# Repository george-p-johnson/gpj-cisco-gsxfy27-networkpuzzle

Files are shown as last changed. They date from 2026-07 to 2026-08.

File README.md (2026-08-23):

# Arduino Resistor Match Question/Answer Game: System Reference & Guide

> **This file describes the original single-board prototype and is out of date.** The live installation runs six boards driven by a shared `answer_table.tsv` answer key (not the hardcoded `correctAnswers[3]` array below), plus a networked remote controller and admin status page. See [`question_game/CLAUDE.md`](question_game/CLAUDE.md) for the current system, and [`remote_controller/README.md`](remote_controller/README.md) for the remote controller / admin page. The electrical design, ADC signal processing, and calibration math below (Sections 2-4) are still accurate and unchanged.

This file provides the comprehensive architectural, electrical, mathematical, and programmatic specification for the 3-Channel Resistor Match Question/Answer Game powered by the **Waveshare ESP32-S3** microcontroller. It is fully self-contained and serves as the single source of truth for understanding, modifying, or reproducing this system.

---

## 1. System Overview & Game Mechanics

The project implements a hardware-based, tactile matching game featuring **three question sockets** (channels) and corresponding **answer sockets**. 

* **The Patch Cord Interface:** A physical patch cord (carrying an embedded test resistor representing the selected answer) is plugged between a question socket and an answer socket.
* **Continuous Scanning:** The microcontroller continuously scans the three question sockets to identify which answer resistor (if any) is currently connected.
* **Match Indicator LEDs:** Each channel has a dedicated bi-color LED:
  - **Green LED:** Illuminates when the patch cord connects a question socket to its **correct** answer socket (as defined in software).
  - **Red LED:** Illuminates if the patch cord is connected to an **incorrect** answer socket, or is **unplugged** (open circuit).
* **Game Victory State:** A game-wide success signal is triggered only when all three channels have correct matches simultaneously.
* **Variable Configurations:** To allow questions to change dynamically from game to game, correct answers are stored in a simple, editable software array. This enables rapid game reconfigurability without any hardware rewiring.

---

## 2. Hardware Architecture & Electrical Design

The system determines matches by measuring the voltage drop across a custom voltage divider network.

### A. Circuit Diagram
Each of the three channels utilizes an identical, noise-insulated voltage divider circuit designed to stabilize readings and prevent capacitive/electrostatic interference:

```
                  +3.3V (VCC)
                    |
              [ 10k Ω Fixed ]  <--- Top Reference Resistor (R_top)
                    |
                    +-------------------> ESP32-S3 Analog Pin (GPIO 1, 2, or 3)
                    |               |
             [ Test Resistor ]   [ 100k Ω ] <--- Permanent Pull-Down Resistor (R_PD)
                 (R_test)          (R_PD)
                    |               |
                   GND             GND
```

### B. Component Role & Optimization Choices
* **Top Reference Resistor ($R_{\text{top}}$) = $10\text{ k}\Omega$:** Sits at the geometric center of our target resistor range ($470\ \Omega$ to $100\text{ k}\Omega$). This balances voltage step intervals across low and high values, preventing low-value resistors from falling into the ground noise floor and high-value resistors from compressing near the ADC saturation ceiling.
* **Permanent Pull-Down Resistor ($R_{\text{PD}}$) = $100\text{ k}\Omega$:** 
  - Prevents the analog pin from floating when a patch cord is unplugged. 
  - Forms a baseline voltage divider when the socket is empty (Open Circuit), locking the baseline reading cleanly at $\approx 3040\text{ mV}$.
  - Pulls high-end test values down, expanding the spacing between the highest resistor ($100\text{ k}\Omega$) and an open circuit into a wide, easily detectable $+238\text{ mV}$ gap.
* **Test Socket Resistor ($R_{\text{test}}$):** Placed in the answer socket. When plugged, it sits in parallel with the $100\text{ k}\Omega$ pull-down.

### C. Mathematical Model
When a patch cord is inserted, the lower resistance branch ($R_{\text{bottom}}$) becomes the parallel combination of the test resistor ($R_{\text{test}}$) and the permanent pull-down ($R_{\text{PD}}$):

$$R_{\text{bottom}} = \frac{R_{\text{test}} \times 100,000}{R_{\text{test}} + 100,000}$$

The voltage output ($V_{\text{out}}$) delivered to the ESP32-S3 ADC is:

$$V_{\text{out}} = 3300\text{ mV} \times \frac{R_{\text{bottom}}}{10,000 + R_{\text{bottom}}}$$

---

## 3. Signal Processing & ESP32-S3 ADC Workarounds

The ESP32-S3 features a successive-approximation register (SAR) ADC. Utilizing this hardware reliably across multiple rapid channels requires specific software workarounds.

### A. Multiplexer Residual Charge Flush
* **The Issue:** The ESP32-S3 shares a single internal ADC across its input pins. Rapidly switching the internal multiplexer between pins causes residual capacitive charge from the previous pin to leak into the next channel's measurement, producing false matches.
* **The Solution:** The reading function performs a single "throwaway" read (`analogReadMilliVolts(pin)`) and pauses for $100\ \mu\text{s}$ (`delayMicroseconds(100)`) to allow the multiplexer's internal capacitance to fully discharge before sampling.

### B. ADC Settings & Filtering
* **ADC Settings:** 12-bit resolution (`0` to `4095`) and $11\text{dB}$ attenuation (`ADC_11db`), mapping the input range across the full $0\text{V} - 3.3\text{V}$ scale.
* **Filtering Noise:** To smooth high-frequency voltage fluctuations and EMI, the software averages 15 separate ADC samples over a $15\text{ms}$ interval for each channel.
* **Noise Floor:** Any voltage reading below $75\text{ mV}$ is explicitly discarded as skin-touch capacitive noise or stray ground loop voltage and mapped to `NONE`.

---

## 4. Adaptive Calibration & Auto-Span Architecture

Rather than relying on brittle, hardcoded threshold numbers, the firmware implements a professional, self-normalizing hardware-calibration pipeline.

### A. Measured Ranges Database
Your raw, physical measurements are stored as a static array of range structures (`minMV` and `maxMV`) normalized to a standard $3300\text{ mV}$ rail scale:

| Resistor Class | Your Empirical Range | Calculated Gap Midpoint |
| :--- | :---: | :---: |
| **Noise / Touch** | $0 - 74\text{ mV}$ | — |
| **$470\ \Omega$** | $112 - 186\text{ mV}$ | $218\text{ mV}$ |
| **$1\text{ k}\Omega$** | $250 - 326\text{ mV}$ | $432\text{ mV}$ |
| **$2.2\text{ k}\Omega$** | $539 - 608\text{ mV}$ | $787\text{ mV}$ |
| **$4.7\text{ k}\Omega$** | $967 - 1041\text{ mV}$ | $1283\text{ mV}$ |
| **$10\text{ k}\Omega$** | $1525 - 1596\text{ mV}$ | $1837\text{ mV}$ |
| **$22\text{ k}\Omega$** | $2078 - 2131\text{ mV}$ | $2215\text{ mV}$ |
| **$33\text{ k}\Omega$** | $2300 - 2374\text{ mV}$ | $2387\text{ mV}$ |
| **$47\text{ k}\Omega$** | $2401 - 2551\text{ mV}$ | $2583\text{ mV}$ |
| **$68\text{ k}\Omega$** | $2615 - 2682\text{ mV}$ | $2703\text{ mV}$ |
| **$100\text{ k}\Omega$** | $2725 - 2803\text{ mV}$ | $2921\text{ mV}$ |
| **NONE (Open)** | $\approx 3040\text{ mV}$ | $> 2921\text{ mV}$ |

You can easily tweak these ranges directly inside the `nominalRanges[]` array in the Arduino IDE if physical components are changed!

### B. Runtime Boundary Calculation & Threshold Bias
The software automatically calculates decision boundaries between adjacent resistors at runtime:
$$\text{Threshold}[i] = \text{Max}_i + (\text{Min}_{i+1} - \text{Max}_i) \times \text{THRESHOLD\_BIAS}$$

* **`THRESHOLD_BIAS` parameter (Default: `0.3`):** This customizable constant defines where the boundary is placed within the unassigned gaps.
  - Setting it to `0.5` places boundaries exactly in the mathematical center (midpoint).
  - Setting it to `0.3` biases thresholds lower in the gap (closer to the lower resistor). This gives the higher resistor a massive **downward safety cushion** to tolerate loose wires, power supply dips, or resistor tolerances without misclassifying!

### C. Continuous & Startup Auto-Span Calibration
To completely neutralize chip-to-chip and pin-to-pin ADC gain variations, the software runs an intelligent calibration loop:

1. **Boot-Time reference Scan:** When the ESP32-S3 starts, the program scans all three pins. If you boot with patch cables already plugged in, it searches for any **single empty pin** (reading $> 2850\text{ mV}$) to compute the chip's global scale factor and instantly calibrates *all three* channels on startup. If all three channels are plugged on boot, it defaults to a scale factor of `1.0`.
2. **Continuous Normalization:** Whenever a pin becomes empty during gameplay, the system dynamically measures the raw open-circuit voltage $V_{\text{raw\_open}}$ and updates its scale multiplier.
3. **Aligned Target:** The calibration standard target is aligned to **`3040.0 mV`** (your physical board's natural open baseline). This ensures that on your hardware, the scale factors naturally calibrate to exactly `1.0`, resulting in $100\%$ consistent behavior whether you boot with cables plugged or unplugged:
$$\text{scaleFactor}[i] = \frac{3040.0}{V_{\text{raw\_open}}[i]}$$
All subsequent resistor readings on Pin $i$ are multiplied by `scaleFactor[i]` before classification. This guarantees that all three sockets behave identically on any physical board!

---

## 5. Hardware Pin Mapping

The system relies on three discrete analog inputs and six digital output pins mapped to physical bi-color LEDs.

| Channel | physical Socket | ESP32-S3 Pin | LED RED GPIO | LED GREEN GPIO | Physical Header Pins & Location |
| :---: | :---: | :---: | :---: | :---: | :--- |
| **CH1** | Socket 1 | **GPIO 1** | **GPIO 16** | **GPIO 17** | Left Header Pins 32, 34 |
| **CH2** | Socket 2 | **GPIO 2** | **GPIO 38** | **GPIO 39** | Right Header Pins 14, 12 |
| **CH3** | Socket 3 | **GPIO 3** | **GPIO 34** | **GPIO 35** | Right Header Pins 19, 17 |

*Note: LED pins output digital `HIGH` to switch the selected color ON, and `LOW` to switch it OFF. Red and Green pins are operated mutually-exclusively per channel.*

---

## 6. Software Architecture & Game Flow

The game is structured using a simple polling-loop state machine. 

### A. Variable Array Structure
The core flexibility requirement is achieved through the global configuration array `correctAnswers[3]`. Each element stores the target resistor index corresponding to a specific channel:

```cpp
// Target resistor index matching table (0 = 470, 1 = 1k, ... 9 = 100k)
int correctAnswers[3] = {
  3,  // CH1 expects 4.7k (Index 3)
  7,  // CH2 expects 47k  (Index 7)
  5   // CH3 expects 22k  (Index 5)
};
```

### B. Logic Processing Flow
On every iteration of the `loop()`:
1. **Reset Victory Tracker:** A boolean flag `allCorrect` is initialized to `true`.
2. **Channel Polling:** For each channel `i` from `0` to `2`:
   - Measure the smoothed analog voltage ($V_{\text{out}}$) on `ANALOG_PINS[i]` after flushing the charge.
   - Map the voltage value to its resistor classification index `detectedIndex` using the Midpoint Decision boundaries.
   - Compare `detectedIndex` with the target `correctAnswers[i]`.
   - Update LEDs:
     - If matched (`detectedIndex == correctAnswers[i]`), set Green Pin `HIGH` and Red Pin `LOW`.
     - If mismatched or unplugged, set Red Pin `HIGH` and Green Pin `LOW`, and toggle `allCorrect = false`.
   - Output Serial telemetry details (measured mV, detected resistor name, match status).
3. **Master Win Assertion:** If `allCorrect` remains `true` after polling all three channels, output the unified game win telemetry (`*** GAME SOLVED: ALL PATCHES CORRECT! ***`).
4. **Throttle Delay:** A final $300\text{ms}$ delay throttles the scanning loop to conserve processing cycles and provide human-readable serial logs.

---

## 7. Operational Instructions for Game Administrators

### Changing Answers for a New Game
To re-index answers for a brand new game session:
1. Choose which physical answer resistor value should match each physical question socket (CH1, CH2, CH3).
2. Look up each resistor's **Index** from the **Adaptive Calibration & Auto-Span Database** (Section 4).
3. Locate the `correctAnswers[3]` array near the top of `question_game.ino`.
4. Update the indices in the array. For example, if you want:
   - CH1 to match $1\text{ k}\Omega$ (Index `1`)
   - CH2 to match $100\text{ k}\Omega$ (Index `9`)
   - CH3 to match $2.2\text{ k}\Omega$ (Index `2`)
   
   Modify the line to:
   ```cpp
   int correctAnswers[3] = { 1, 9, 2 };
   ```
5. Upload the sketch to the ESP32-S3 Dev Board. No physical circuit changes are necessary.

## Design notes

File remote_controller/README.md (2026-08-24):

# Remote Controller

A small web app for operating the GSXFY27 Network Puzzle game from a phone,
tablet, or laptop on the same network as the show PC.

- 3 toggle buttons: **Activate Player 1 / 2 / 3** (only enabled while the game state is Idle *and* that player's boards are online -- Player 1 needs boards 1/2, Player 2 needs boards 3/4, Player 3 needs boards 5/6; shows "NO BOARDS" otherwise)
- 2 pulse buttons: **Start Game** (only enabled while the game state is Idle, at least one player is active, *and* no board has a patch cord still plugged in from the previous game -- shows a docent-facing reminder naming exactly which player/question is still connected, e.g. "Player 2 Q4", otherwise), **Reset Game** (also auto-activates any player not already ON *and* whose boards are online, so a fresh reset defaults to all reachable players ready)
- A live **Connected / Disconnected** indicator for the link to TouchDesigner
- A live **game state** display (Idle / Three / Two / One / Start / Gameplay / Results)
- A live **Boards** indicator showing which of the 6 ESP32 question boards are currently reporting, grouped by panel
- A **Show Answer Key** toggle, collapsed by default, revealing each player's Q1-Q6 answer socket and resistor value (e.g. "Q3 -> Socket A7, 47kΩ") for a docent to reference on the floor. Read once from `answer_table.tsv` at server launch (same restart-to-reload caveat as the admin page's answer data, see below) and sent to every client on the public page -- deliberately not admin-gated, since the docent is this page's primary user, even though the page is also reachable off the LAN per `DEPLOYMENT.md`.

It runs as a small Node.js server on the same Windows PC as TouchDesigner:
the server hosts the control page over plain HTTP/WebSocket for any device
on the LAN, and separately speaks OSC/UDP to TouchDesigner (matching the
OSC convention the ESP32 boards already use, on different ports so it never
touches port 9000).

```
Browser  <--WebSocket-->  Node server  <--OSC/UDP-->  TouchDesigner
(any LAN device)          (this PC)                    (this PC)
```

## Setup

```bash
npm install
cp .env.example .env
```

Edit `.env` if you want a different HTTP port (default `8080`) or different
OSC ports. See [`.env.example`](.env.example) for all options.

## Run

```bash
npm start
```

The console prints the URLs to use:

```
Local:   http://localhost:8080
Network: http://192.168.x.x:8080
```

Open the `Network` URL from any phone/tablet/laptop on the same network as
the show PC.

## TouchDesigner side

See [`touchdesigner/SETUP.md`](touchdesigner/SETUP.md) for the OSC In DAT /
Callbacks DAT / heartbeat wiring needed inside the `.toe` to receive
commands and report connection status back.

## Show PC deployment

See [`DEPLOYMENT.md`](DEPLOYMENT.md) for how this is made reachable from
outside the LAN (Cloudflare Tunnel, `https://gsxnetworkpuzzle.com`) and how
the show PC autostarts everything, with crash auto-recovery
(`../START_CISCO_NETWORK_PUZZLE.bat` + Task Scheduler).

## Message reference

| UI action | OSC address (Remote → TD) | Value |
| --- | --- | --- |
| Toggle Player 1/2/3 | `/remote/player/1`, `/2`, `/3` | `1` = on, `0` = off |
| Start Game | `/remote/start_game` | `1` |
| Reset Game | `/remote/reset_game` | `1` |
| Open Monitors *(admin page only)* | `/remote/open_monitors` | `1` |
| Reset Best Time *(admin page only)* | `/remote/reset_best_time` | `1` |

Reset Game also triggers up to three additional `/remote/player/<n>` = `1`
messages right after it (staggered `PLAYER_ACTIVATE_STAGGER_MS` apart, see
`.env.example`) — one for each player not already active, so TD sees the
same activation messages it would if someone had toggled them by hand.

| TD → Remote | OSC address | Purpose |
| --- | --- | --- |
| Heartbeat | `/remote/heartbeat` | Sent ~every 1s; drives Connected/Disconnected |
| Game state | `/remote/game_state` | Int `1`-`7`; drives the game-state display |
| Player active | `/remote/player_active` | 3 ints `[p1, p2, p3]` as 0/1; authoritative -- overwrites the server's local player state on receipt (see below) |
| Player result | `/remote/player_result` | 3 ints `[p1, p2, p3]`, placement code `0`-`3`: `0` = Try Again, `1` = Winner, `2` = 2nd place, `3` = 3rd place. TD flips `1`-`3` live per player as they finish during Gameplay; `0` is set for anyone still unfinished at the Gameplay->Results boundary once time runs out. Drives the WINNER/2ND PLACE/3RD PLACE/TRY AGAIN label on each active player's button, shown only while game state is Gameplay or Results (otherwise the plain ON/OFF/NO BOARDS label is shown, ignoring any stale placement from a previous round) |
| Board status | `/remote/waveshare/1` ... `/remote/waveshare/6` | `1` = board reporting recently, `0` = stale/offline; drives the Boards indicator, and (paired up) the per-player `boardsReady` flags below |
| Board detail | `/remote/waveshare_detail/1` ... `/6` | 3 ints: `ch1Index, ch2Index, ch3Index` (0-10 resistor classification, see below) -- raw per-channel readings power the private admin status page only |

Board status also drives a public, non-admin-gated `boardsReady` map in the
state broadcast: Player 1 is ready only when boards 1 *and* 2 are both
reporting, Player 2 needs boards 3/4, Player 3 needs boards 5/6 (same
board->panel mapping as `question_game/CLAUDE.md` Section 6D). A player
whose boards aren't ready has its **Activate Player N** button disabled
(shown as "NO BOARDS") even while the game state is Idle, and is skipped by
Reset Game's auto-activate. The server also rejects a `toggle` trying to
turn that player ON outright, so this can't be bypassed by a stale/cached
page -- though an already-active player can still be toggled back OFF if its
boards drop out mid-idle.

Board detail also drives two public, non-admin-gated derived fields:
* `anyConnected` -- `true` whenever any channel on any board reads other
  than `10` (NONE) -- i.e. something is still plugged in somewhere. This
  blocks the **Start Game** button and shows the docent reminder above
  (server also rejects a `start_game` pulse outright while it's true, so
  this can't be bypassed by a stale/cached page).
* `connectedCables` -- an array of `{ player, question }` pairs (question
  `1`-`6`) naming exactly which sockets are still plugged in, rendered under
  the docent reminder (e.g. "Player 2 Q4, Player 3 Q1"). Both fields are
  presence-only -- neither reveals which resistor is plugged in or whether
  it's correct, so both are safe to send to every connected client, not just
  admin ones.

Resistor classification index (same 0-10 scale the ESP32 firmware uses and
the admin page translates to a label -- see `public-admin/app.js`
`RESISTOR_LABELS`):

| Index | Resistor |
| :---: | --- |
| 0 | 470Ω |
| 1 | 1kΩ |
| 2 | 2.2kΩ |
| 3 | 4.7kΩ |
| 4 | 10kΩ |
| 5 | 22kΩ |
| 6 | 33kΩ |
| 7 | 47kΩ |
| 8 | 68kΩ |
| 9 | 100kΩ |
| 10 | NONE (socket empty / open circuit) |

Game state values:

| Value | State |
| :---: | --- |
| 1 | Idle |
| 2 | Three |
| 3 | Two |
| 4 | One |
| 5 | Start |
| 6 | Gameplay |
| 7 | Results |

Toggle state and the last-known game state are held centrally on the Node
server, so every connected browser stays in sync if more than one person
has the page open. Player state specifically is also confirmed by TD
(`/remote/player_active`, not just assumed from the last command the server
sent) -- otherwise a server restart would show every player OFF regardless
of what TD actually had active, since the server's own memory resets to
all-OFF on startup. See `touchdesigner/SETUP.md` Section 5c for the TD-side
wiring.

## Private admin status page

`public-admin/` is a second, separate page showing each board's live
resistor-classification reading per question (Q1-Q3 or Q4-Q6 depending on
the board, translated from the 0-10 index to a resistor value, e.g. "33kΩ"),
grouped by Player 1/2/3 -- e.g. to check whether Q4 on Player 2's boards is
plugged into the right resistor. It also carries the
**Open Monitors** and **Reset Best Time** pulse buttons, moved here from the
public control page since they're maintenance actions, not something a
random visitor to the public URL should be able to trigger. TD only sends the raw
classification (no match data), so the server reads the correct-answer key
itself: once at launch, from `answer_table.tsv` at the repo root (the same
file the ESP32 boards' SD cards read from -- see `server.js`
`loadAnswerIndex()`) and sends it to admin clients alongside the live
readings. **Editing `answer_table.tsv` needs a server restart to take
effect** -- it's read once at startup, not watched for changes. It's only
served to requests whose `Host` header matches `ADMIN_HOSTNAME` (`.env`, default
`admin.gsxnetworkpuzzle.com`); any other hostname never sees that directory.
See `touchdesigner/SETUP.md` Section 4b for the TD-side wiring this needs,
and `DEPLOYMENT.md` for exposing it as its own subdomain through the
Cloudflare Tunnel.

Every response served on the admin hostname carries `Cache-Control: no-store`
(both browser and Cloudflare-edge caching disabled) -- this page changes
often during development, and a cached `app.js` will keep running old logic
against new data long after the server's been updated (e.g. rendering a
field the current code no longer sends). The public control page is
unaffected and keeps normal caching.

**`no-store` only prevents *new* staleness -- it doesn't retroactively clear
copies Cloudflare's edge had already cached from before that header
existed.** Confirmed in practice: after adding `no-store` and deploying an
`app.js` change, some clients still received the old file -- a hard refresh
on the affected device wasn't enough, but Cloudflare edge nodes are
per-location, so different visitors can be served from different (stale vs.
fresh) edges simultaneously. Fix: **Cloudflare dashboard → Caching →
Configuration → Purge Everything** (or a Custom Purge of
`admin.gsxnetworkpuzzle.com/*`). This is a global edge purge and needs
dashboard access -- there's no CLI/API token set up for it in this project,
so it has to be done manually when it comes up.

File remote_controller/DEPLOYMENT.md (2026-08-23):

# Show PC deployment: public access + autostart

This covers the parts of the setup that live outside the app itself: making
the remote controller reachable from a phone/iPad without needing to be on
the same network as the show PC, and getting everything running
automatically when the show PC boots.

## Why a public tunnel, not just the LAN

Convention center networks are frequently locked down in ways that break
plain LAN access between devices on the same Wi-Fi (client isolation is
common, specifically to stop one attendee's device from reaching another's)
-- and bringing your own router/AP to create a private LAN may not be
usable or permitted on the show floor. A Cloudflare Tunnel sidesteps this
entirely: the show PC makes an *outbound* connection to Cloudflare (almost
always allowed, even on locked-down guest networks), and the control device
just opens a normal HTTPS URL over its own internet connection (venue
Wi-Fi or cellular) -- neither device needs to reach the other directly, so
network topology at the venue stops mattering.

The tradeoff: this depends on the venue actually having usable outbound
internet. The travel router is the fallback if that turns out not to be
true on-site.

## Current setup

- **Public URL:** `https://gsxnetworkpuzzle.com` (domain registered on
  Namecheap, DNS hosted on Cloudflare, free plan)
- **Tunnel name:** `gsx-remote-controller`
- **Tunnel ID:** `39103a87-015e-4755-9714-8158f1eb55c2`
- **cloudflared config (used by the service):** `C:\ProgramData\Cloudflare\cloudflared\config.yml`
  (points the `gsxnetworkpuzzle.com` hostname at `http://127.0.0.1:8080`,
  i.e. the remote-controller server -- `127.0.0.1` specifically, not
  `localhost`; see the gotcha below)
- **Credentials file (service copy):** `C:\ProgramData\Cloudflare\cloudflared\39103a87-015e-4755-9714-8158f1eb55c2.json`
  (keep this private -- it's what authorizes the tunnel; if it ever leaks,
  delete the tunnel via the Cloudflare dashboard to revoke it)
- A second copy of both files lives under `C:\Users\Spaceship\.cloudflared\`
  from initial setup/manual testing -- harmless to leave, just not what the
  service actually reads.
- **cloudflared install:** `C:\Program Files (x86)\cloudflared\cloudflared.exe`
  (installed via `winget install --id Cloudflare.cloudflared -e`)
- Only the bare domain is routed (no `www`) -- that was a deliberate choice,
  not an oversight.

Runs as a **Windows service** (auto-starts at boot, and the Service Control
Manager can restart it automatically if it crashes -- more resilient than
launching it from a startup script, which has no self-healing if the
process dies mid-show).

### The two non-obvious gotchas that cost real time getting this working

**1. `cloudflared service install` does not support `--config`, and its
default config auto-discovery does not reliably find a config placed in
either the interactive user's `~/.cloudflared/` or (despite some
documentation implying otherwise) `C:\ProgramData\Cloudflare\cloudflared\`
when running under the `LocalSystem` account it installs as.** Passing
`--config` before `service install` is silently ignored -- its own
`--help` only documents an optional `[TOKEN]` argument (for
Cloudflare-dashboard-managed tunnels, not our locally-created named
tunnel). The service would start, show `RUNNING`, and never actually
connect to Cloudflare's edge (0 network connections, requests to the
public URL returned a `530` -- "no active connector") with no error
surfaced anywhere obvious.

**The fix:** point the service's actual launch command at the config file
directly, by editing its registry `ImagePath` (this is more reliable than
`sc.exe config Cloudflared binPath= "..."`, which is the "normal" way to
do this -- that command kept silently failing to apply, almost certainly
PowerShell mangling the nested quotes on their way to the native `sc.exe`
argument parser):

```powershell
# Run as Administrator
Set-ItemProperty -Path "HKLM:\SYSTEM\CurrentControlSet\Services\Cloudflared" -Name "ImagePath" `
  -Value '"C:\Program Files (x86)\cloudflared\cloudflared.exe" --config "C:\ProgramData\Cloudflare\cloudflared\config.yml" tunnel run'
Get-Process cloudflared | Stop-Process -Force
Start-Sleep -Seconds 2
Start-Service -Name Cloudflared
sc.exe qc Cloudflared   # BINARY_PATH_NAME should now show the full command with --config
```

**2. Use `127.0.0.1`, not `localhost`, in `config.yml`'s `service:` line.**
`localhost` can resolve differently (IPv4 vs IPv6 loopback) under the
`LocalSystem` account's network context than under an interactive user
session -- worked fine testing manually as a normal user, returned `502
Bad Gateway` (tunnel connected fine, couldn't reach the origin) once
running as the actual service. Switching to the literal `127.0.0.1`
resolved it.

### Recreating this from scratch (e.g. new PC, or the credentials leaked)

1. `cloudflared tunnel login` -- opens a browser, authorize against the
   Cloudflare account, select the zone (`gsxnetworkpuzzle.com`).
2. `cloudflared tunnel create <name>` -- writes a new credentials JSON to
   `~/.cloudflared/`.
3. `cloudflared tunnel route dns <name> gsxnetworkpuzzle.com` -- if this
   fails with "record already exists," delete the conflicting DNS record
   for the bare domain in the Cloudflare dashboard first (a parking-page
   record commonly gets imported automatically when a domain is first
   added to Cloudflare).
4. Create `C:\ProgramData\Cloudflare\cloudflared\` and place `config.yml`
   there (see the current one for the exact format -- `tunnel:`/
   `credentials-file:` pointing at the new tunnel's ID/JSON, `ingress`
   rule mapping `gsxnetworkpuzzle.com` → `http://127.0.0.1:8080` --
   **`127.0.0.1`, not `localhost`**), plus a copy of the credentials JSON
   in that same folder.
5. `cloudflared service install` (as Administrator) -- installs the
   service shell; don't expect it to actually work yet.
6. Apply the registry `ImagePath` fix from gotcha #1 above, then restart
   the service and confirm with `sc.exe qc Cloudflared` before trusting it.
7. Verify end-to-end: `Invoke-WebRequest https://gsxnetworkpuzzle.com`
   should return `200`, not `530` (dead tunnel) or `502` (tunnel up,
   origin unreachable).

## Admin status subdomain (`admin.gsxnetworkpuzzle.com`)

The remote controller's private per-socket status page (`public-admin/` --
see `touchdesigner/SETUP.md` Section 4b) is gated by hostname: it's only
served to requests whose `Host` header is exactly `ADMIN_HOSTNAME` (`.env`,
default `admin.gsxnetworkpuzzle.com`). Any other hostname -- including the
main public one -- gets the normal control page and never sees the admin
directory, so there's no path to guess. This is obscurity, not
authentication: anyone who learns the admin hostname can load it with no
login. Don't post/share it anywhere public.

Both hostnames route through the same tunnel to the same origin
(`http://127.0.0.1:8080` -- the Node server itself decides which page to
serve based on the `Host` header it receives), so adding the subdomain is
just another `ingress` rule + DNS route on the tunnel that already exists:

1. Add a second hostname rule to
   `C:\ProgramData\Cloudflare\cloudflared\config.yml`, **above** the
   catch-all `http_status:404` rule (ingress rules are matched top to
   bottom, first match wins):

   ```yaml
   tunnel: 39103a87-015e-4755-9714-8158f1eb55c2
   credentials-file: C:\ProgramData\Cloudflare\cloudflared\39103a87-015e-4755-9714-8158f1eb55c2.json

   ingress:
     - hostname: gsxnetworkpuzzle.com
       service: http://127.0.0.1:8080
     - hostname: admin.gsxnetworkpuzzle.com
       service: http://127.0.0.1:8080
     - service: http_status:404
   ```

2. Route DNS for the new hostname to the same tunnel:

   ```powershell
   cloudflared tunnel route dns gsx-remote-controller admin.gsxnetworkpuzzle.com
   ```

3. Restart the service so it picks up the new config:

   ```powershell
   Get-Process cloudflared | Stop-Process -Force
   Start-Sleep -Seconds 2
   Start-Service -Name Cloudflared
   ```

4. Verify: `https://admin.gsxnetworkpuzzle.com` should show the board status
   page; `https://gsxnetworkpuzzle.com` should still show the normal control
   page and must **not** show admin content at any path.

Local testing without touching the tunnel: `curl -H "Host: admin.gsxnetworkpuzzle.com" http://localhost:8080/`
serves the admin page directly from the Node server, no DNS/tunnel changes
needed.

## Autostart: `START_CISCO_NETWORK_PUZZLE.bat`

[`../START_CISCO_NETWORK_PUZZLE.bat`](../START_CISCO_NETWORK_PUZZLE.bat)
(project root; this is what's wired into Task Scheduler) launches, in order:
1. [`../run_server_watchdog.bat`](../run_server_watchdog.bat), in its own window.
2. A 3-second wait for the server to bind its ports.
3. [`../run_td_watchdog.bat`](../run_td_watchdog.bat), in its own window.

It does **not** launch the Cloudflare tunnel -- that's the Windows service
above, which starts independently at boot. Only add a tunnel line back into
this script if the service is ever uninstalled; running both at once means
two redundant tunnel processes.

### Why watchdog wrappers instead of launching node/TD directly

Neither the Node server nor TouchDesigner self-heals if it crashes mid-show
-- unlike the Cloudflare tunnel, which has Windows Service Control Manager
recovery. `run_server_watchdog.bat` and `run_td_watchdog.bat` each loop
`start /wait` around their respective process: if it ever exits for any
reason, the watchdog waits 5 seconds and relaunches it automatically,
logging each attempt with a timestamp so a crash loop is visible rather
than silent.

**This means closing the app itself doesn't stop it** -- the watchdog just
brings it back. To actually shut something down (e.g. end-of-night
teardown), close the **watchdog's own console window** first (titled "GSX
Remote Controller (watchdog)" / "TouchDesigner (watchdog)"), *then* close
the app. Closing them in the other order just makes the app pop back open.

### Wiring it to Task Scheduler

Create a task pointing at `START_CISCO_NETWORK_PUZZLE.bat` with trigger
**"At log on"** -- not the generic "At startup" trigger. A plain
system-startup trigger runs in Session 0, which has no visible desktop, so
none of these windows would actually appear. Also check **"Run only when
user is logged on"** in the task's General tab, for the same reason.

**Confirmed working** on a real reboot: the Task Scheduler task fired, the
server bound port 8080, TD launched with the project loaded, and TD's
heartbeat reached the server (remote page showed Connected/Idle) -- all
without any manual intervention.

### If the site is down and isn't coming back on its own

The auto-recovery above only works while the watchdog console window itself
is still running -- if *that* window got closed (crashed, closed by
accident, closed in the wrong order during a manual restart), the inner
`node server.js` process it was supervising has no way to come back on its
own, no matter how long you wait.

Check for both **before** assuming the server crashed for some deeper reason:
- Is a `node.exe` process bound to port 8080? (`netstat -ano | findstr ":8080"`)
- Is the **"GSX Remote Controller (auto-restart)"** console window still open?

If the node process is gone and so is its watchdog window, don't just run
`node server.js` directly -- that gets the site back up but leaves it
unsupervised again (a second crash won't self-heal). Instead relaunch the
watchdog script itself so recovery is restored:

```powershell
Start-Process -FilePath "run_server_watchdog.bat" -WorkingDirectory "C:\_projects\gpj-cisco-gsxfy27-networkpuzzle"
```

This has happened more than once with no clear root cause identified yet --
if it recurs, worth checking Windows Event Viewer for why the watchdog's
`cmd.exe` itself exited (a plain `:loop ... goto loop` batch script normally
never does, so something external likely killed it).

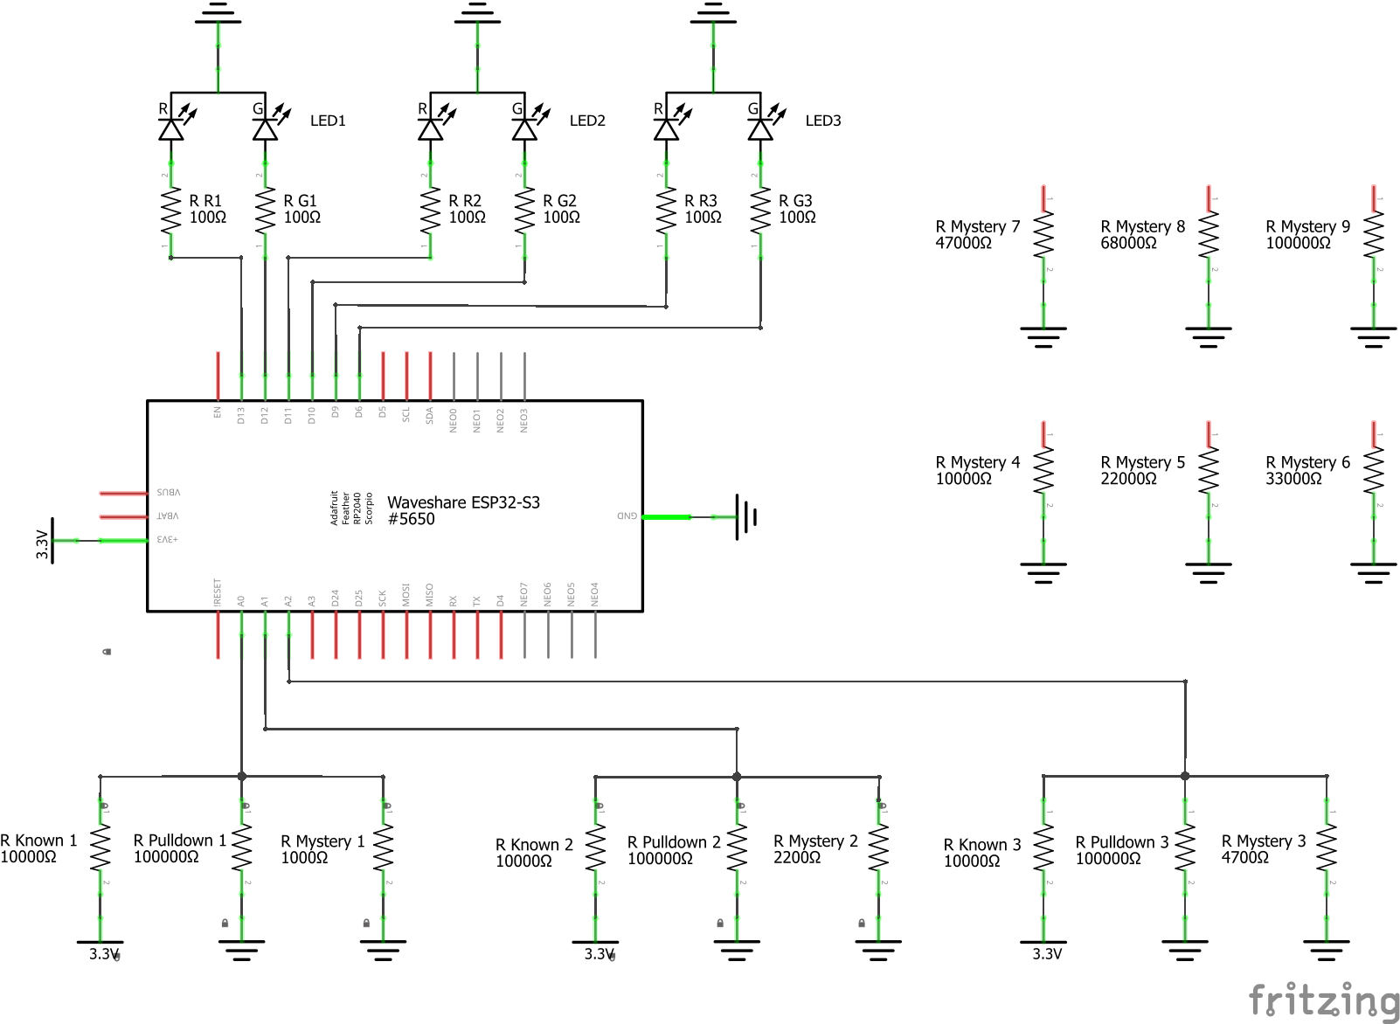
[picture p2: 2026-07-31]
Fritzing/schematic_schem.png

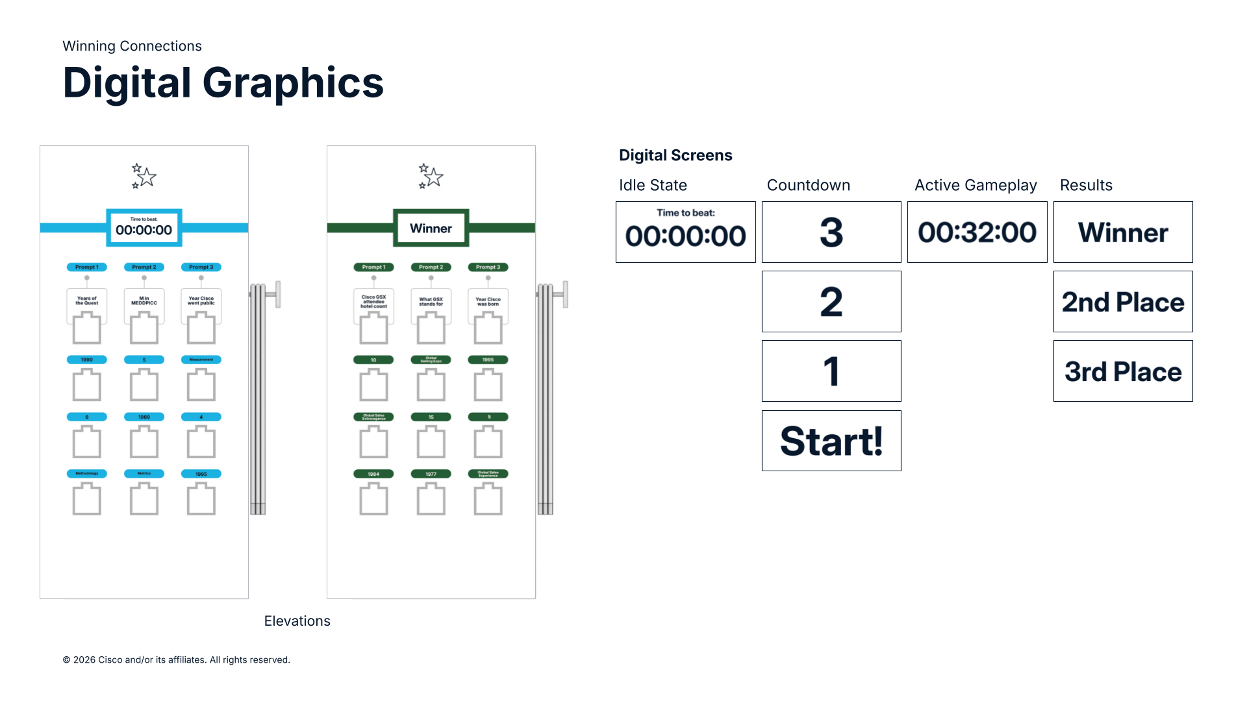
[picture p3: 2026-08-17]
reference/Digital-Graphics.png

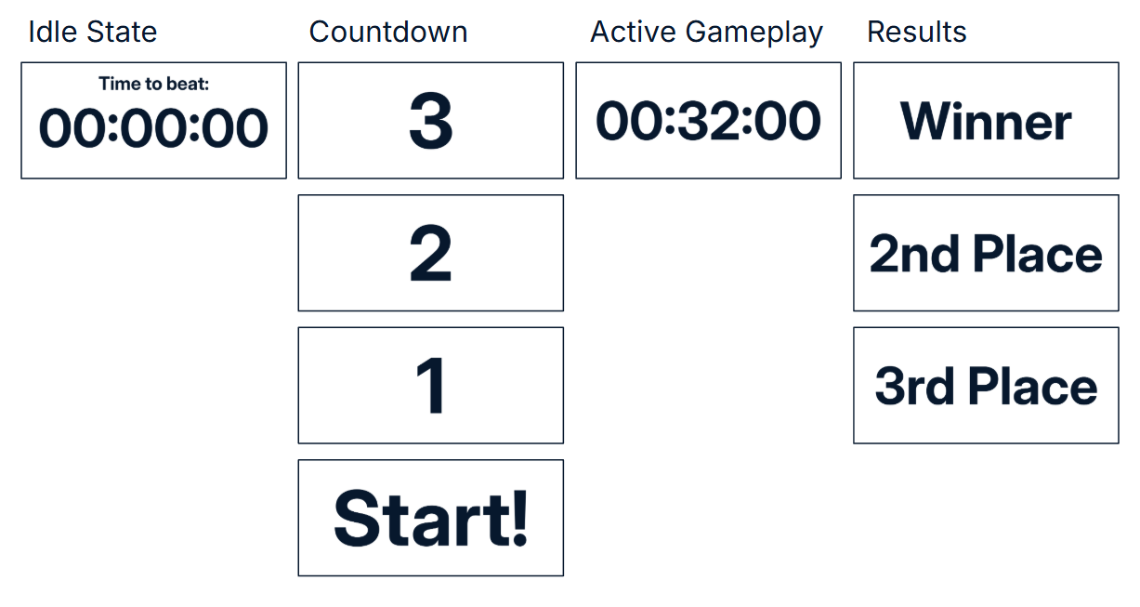
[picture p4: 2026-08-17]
reference/screenlayout.png

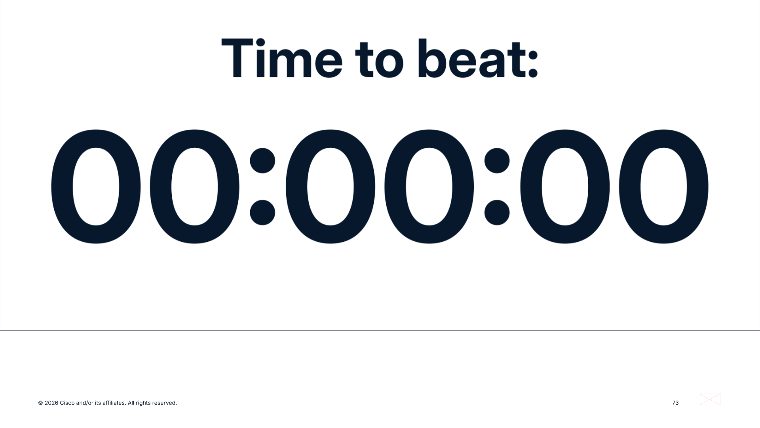
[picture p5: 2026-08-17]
reference/idle-state.png

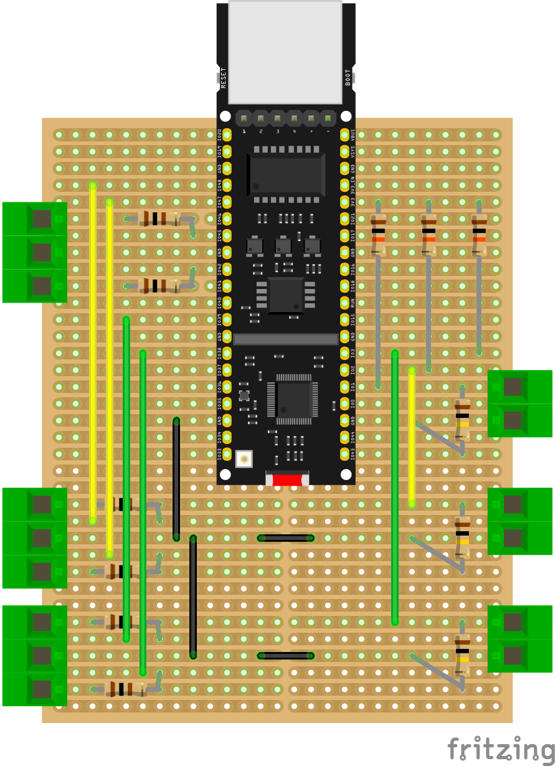
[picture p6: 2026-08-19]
Fritzing/question_game_breadboard_bb.png

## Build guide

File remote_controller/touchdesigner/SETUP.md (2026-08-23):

# Wiring the remote controller into TouchDesigner

The remote controller server talks to TouchDesigner over OSC/UDP, the same
transport already used by the ESP32 boards -- just on different ports so it
never collides with the boards' telemetry on port 9000.

| Direction | Port | Purpose |
| --- | --- | --- |
| Remote → TD | `9001` (UDP) | Button presses (toggles + pulses) |
| TD → Remote | `9002` (UDP) | Heartbeat + current game state |
| TD → Boards | `9003` (UDP, broadcast on `192.168.50.0/24`) | Current game state, for lighting effects |

The first two use loopback (`127.0.0.1`) since the remote server and
TouchDesigner run on the same PC. The third is separate -- it goes out over
the same Ethernet network the boards' own telemetry (port `9000`) arrives
on, to `192.168.50.255` so all six boards receive it with a single send.

Both `.env`-configurable defaults live in [`../.env.example`](../.env.example).

## 1. Receive commands: OSC In DAT

1. Add an **OSC In DAT** to your network (`oscin1`).
2. Set `Network Port` to **9001**.
3. Leave `Local Address` blank (listens on all interfaces) — the remote
   controller connects from `127.0.0.1` since it runs on the same PC.

Each row it outputs has an `address` column like `/remote/player/1` and an
`args` column with the value.

## 2. Dispatch commands: Callbacks DAT (not DAT Execute)

**Use `oscin1`'s own `Callbacks DAT` (`onReceiveOSC`), not a `DAT Execute`
watching its table.** An earlier version of this doc recommended a
`DAT Execute` looping over `oscin1`'s rows on every table change -- that
pattern is broken for a live command stream: if the OSC In DAT retains more
than one row (which it does by default), every new incoming message causes
the loop to *re-process every old row still sitting in the table too*, so a
stale command from minutes ago can fire again alongside a brand new one.
This was actually hit and confirmed live: toggling a player replayed an old
`start_game` command. `onReceiveOSC` fires exactly once per real incoming
packet, with no table/history involved, so this class of bug can't happen.

Select `oscin1` → find its `Callbacks DAT` parameter → create one (this
generates a template with the correct `onReceiveOSC` signature for your TD
build) → fill it in:

```python
# oscin1's Callbacks DAT

def onReceiveOSC(dat, rowIndex, message, bytes, timeStamp, address, args, peer):
    value = int(args[0]) if args else 0

    if address == '/remote/player/1':
        set_player_active(1, value)
    elif address == '/remote/player/2':
        set_player_active(2, value)
    elif address == '/remote/player/3':
        set_player_active(3, value)
    elif address == '/remote/start_game':
        start_game()
    elif address == '/remote/reset_game':
        reset_game()
    elif address == '/remote/open_monitors':
        open_monitors()
    elif address == '/remote/reset_best_time':
        reset_best_time()
    return

def set_player_active(player_num, is_active):
    # TODO: wire to your actual player-activation logic
    debug(f'player {player_num} -> {"ON" if is_active else "OFF"}')

    # Remember it so both the periodic timer (Section 3/5) and this
    # immediate send can read it back -- see Section 5b.
    op('player_active_holder').store('player_%d' % player_num, bool(is_active))
    send_player_active_to_boards()

def start_game():
    # TODO: pulse your Start Game logic
    debug('start_game')

def reset_game():
    # TODO: pulse your Reset Game logic
    debug('reset_game')

def open_monitors():
    # TODO: pulse your Open Monitors logic
    debug('open_monitors')

def reset_best_time():
    # TODO: pulse your Reset Best Time logic
    debug('reset_best_time')
```

Pulse-type commands (`start_game`, `reset_game`, `open_monitors`,
`reset_best_time`) always arrive with value `1` — there's no explicit "off"
message, treat receipt of the message as the pulse itself.

Reset Game additionally causes the remote server to send up to three more
`/remote/player/<n>` messages right after it (staggered ~150ms apart, see
`PLAYER_ACTIVATE_STAGGER_MS` in `.env`) — it auto-activates any player that
wasn't already ON. No special handling needed here: they arrive as ordinary
`/remote/player/<n>` messages through the same callback above.

## 3. Send status back: OSC Out DAT + a Timer/Execute

So the web page can show **Connected**/**Disconnected** and the **current
game state**, TouchDesigner needs to send two small OSC messages back
roughly once a second.

The remote controller understands 7 game-state integers:

| Value | State |
| :---: | --- |
| 1 | Idle |
| 2 | Three |
| 3 | Two |
| 4 | One |
| 5 | Start |
| 6 | Gameplay |
| 7 | Results |

1. Add an **OSC Out DAT** (`oscout_remote`).
   - `Network Address`: `127.0.0.1`
   - `Network Port`: `9002`
2. Add a **Timer CHOP** (or a **Timer COMP**) set to fire every ~1 second,
   with a **CHOP Execute DAT** watching it. On each tick, send both the
   heartbeat and the current state integer (pull the state value from
   wherever your game logic tracks it -- e.g. a Select DAT/CHOP/stored var):

```python
# CHOP Execute callback, watching a 1-second Timer CHOP

def onValueChange(channel, sampleIndex, val, prev):
    op('oscout_remote').sendOSC('/remote/heartbeat', [1])

    # TODO: replace with wherever your game logic stores the current state (1-7)
    current_state = int(op('game_state_holder')['state'])
    op('oscout_remote').sendOSC('/remote/game_state', [current_state])
    return
```

If the remote server doesn't receive a heartbeat for 3 seconds
(`HEARTBEAT_TIMEOUT_MS` in `.env`), it flips every connected browser to
"Disconnected" (the last known game state stays displayed, just grayed out
by the disconnected indicator). Sending `/remote/game_state` on the same
1-second cadence as the heartbeat means a browser that just loaded the page
picks up the correct current state within a second, instead of waiting for
the next actual state transition.

If you'd rather send `/remote/game_state` only when the state actually
changes (event-driven, from whatever callback drives your state machine)
that works too -- just make sure it's also sent once from the same place
the heartbeat timer starts, so a freshly loaded page isn't stuck on "—"
until the next transition.

## 4. Report board (Waveshare) status

The remote page can also show a live/stale indicator for each of the six
ESP32 boards. Board firmware (`question_game.ino`) now sends an 8th int arg,
`heartbeat`, on every `/waveshare/<index>` message -- it increments on every
send regardless of whether the resistor readings changed, so a listener can
tell "board alive, unchanged reading" apart from "board gone". **This
requires reflashing all six boards** with the updated firmware (see
`question_game/CLAUDE.md` Section 9C) before the steps below will work.

Board comms (`oscin_comms`) is an **OSC In CHOP**, so the `heartbeat` arg
lands on its own channel per board (naming depends on your CHOP's
address/split settings -- confirm the actual name with a board sending live
data, e.g. something like `waveshare1_7`; adjust the code below to match).

Rather than timestamping every incoming packet, liveness is decided by
comparing that channel's *current* value against whatever it held on the
*previous* 1-second tick -- since `heartbeat` increments on every send, an
unchanged value between two ticks means the board has gone quiet. This reads
directly on the same timer that already sends `/remote/heartbeat` and
`/remote/game_state` (Section 3); no separate `CHOP Execute DAT` watching
`oscin_comms` is needed:

```python
# Same onCycle callback as Section 3, appended
oscin_boards = op('oscin_comms')
for board in range(1, 7):
    chan_name = 'waveshare%d_7' % board  # <- adjust to your real channel naming
    heartbeat = int(oscin_boards[chan_name].eval()) if chan_name in oscin_boards.chans() else None
    prev_heartbeat = oscin_boards.fetch('prev_heartbeat_%d' % board, None)
    live = heartbeat is not None and heartbeat != prev_heartbeat
    oscin_boards.store('prev_heartbeat_%d' % board, heartbeat)
    op('oscout_remote').sendOSC('/remote/waveshare/%d' % board, [1 if live else 0])
```

A board that's actually gone leaves `oscin_comms` holding its last-received
value forever, so `live` correctly flips to `False` on the very next tick
after it stops sending -- same ~1-second detection window as a timestamp
approach, without needing wall-clock time or a second watcher DAT.

Board index → panel, if you want it to match the physical layout: boards
1-2 are Panel 1 (Player 1), 3-4 are Panel 2 (Player 2), 5-6 are Panel 3
(Player 3) -- same mapping as `question_game/CLAUDE.md` Section 6D. The
remote page's Boards row is already grouped this way.

**If you'd rather not touch `oscin_comms`'s channel-naming assumptions at
all:** the alternative is swapping board comms from an OSC In CHOP to an
OSC In DAT (+ a `DAT to CHOP` downstream for anything that still needs the
old channels), which gets you `onReceiveOSC(address, args)` with `args[7]`
as the heartbeat directly, no channel-name guessing required. More
disruptive to your existing network, but more robust long-term.

## 4b. Forward per-channel readings (private admin status page)

The remote controller has a private status page (`public-admin/`, gated by
`ADMIN_HOSTNAME` -- see `DEPLOYMENT.md`), grouped by Player 1/2/3, that shows
each board's live resistor classification per question, e.g. "is Q4 on
Player 2's boards plugged into 33kΩ." It reads 3 raw index values per board
(0-10, see the resistor scale
in `README.md`) -- just the classification, no match/correctness data.
Pulled straight from the debounced index custom parameters the project
already stores per question (`op.PROJECT.par.Indexp<board>q<channel>`), and
sent on the same 1-second timer:

```python
# Same onCycle callback as Section 3/4, appended
p1q1_idx = int(op.PROJECT.par.Indexp1q1)
p1q2_idx = int(op.PROJECT.par.Indexp1q2)
p1q3_idx = int(op.PROJECT.par.Indexp1q3)
op('oscout_remote').sendOSC('/remote/waveshare_detail/1', [p1q1_idx, p1q2_idx, p1q3_idx])

p2q1_idx = int(op.PROJECT.par.Indexp2q1)
p2q2_idx = int(op.PROJECT.par.Indexp2q2)
p2q3_idx = int(op.PROJECT.par.Indexp2q3)
op('oscout_remote').sendOSC('/remote/waveshare_detail/2', [p2q1_idx, p2q2_idx, p2q3_idx])

# ...same pattern for boards 3-6
```

The 3 values must be in channel order: `ch1Index, ch2Index, ch3Index`. This
is a simpler substitute for the `oscin_comms`-channel-scraping approach an
earlier version of this doc suggested -- if the project already has these
debounced index pars available directly, reading them is more robust than
guessing OSC In CHOP channel names.

## 5. Send game state to the boards (lighting effects)

Board firmware now listens on UDP **9003** for a `/game_state` broadcast
(one int32 arg, same 1-7 convention as everywhere else) and drives its LEDs
accordingly -- **this requires reflashing all six boards** first (see
`question_game/CLAUDE.md` Section 9C). The lighting behavior is baked into
firmware, not something TD controls per-LED -- TD only needs to broadcast
the current state number:

| State | Board lighting behavior |
| --- | --- |
| Idle (1) | Flickering green (mimics an Ethernet switch port's activity LED), regardless of what's plugged in |
| Three (2) | CH1 red, CH2/CH3 off |
| Two (3) | CH1 + CH2 red, CH3 off |
| One (4) | CH1 + CH2 + CH3 red |
| Start (5) | All off |
| Gameplay (6) / Results (7) | Real connection data: green = correct, red = wrong resistor plugged in, off = socket empty |

A board whose player is inactive (see Section 5b below) shows Idle lighting
throughout, regardless of which of the states above the rest of the game is
actually in.

1. Add an **OSC Out DAT** (`oscout_boards`):
   - `Network Address`: `192.168.50.255` (subnet broadcast -- reaches all
     six boards with one send; the boards' own static IPs are
     `192.168.50.11`-`192.168.50.16`, but you don't need to target them
     individually)
   - `Network Port`: `9003`
2. Send `/game_state` on the same 1-second timer as Section 3, and ideally
   also **immediately whenever the state actually changes** rather than
   waiting for the next tick -- the countdown states (Three/Two/One) are
   short, so a full second of latency on the lighting cue would be visibly
   laggy on stage. If your state machine already has a single place where
   the state transitions, fire the send from there too:

   ```python
   # Same onCycle callback as Section 3, appended
   op('oscout_boards').sendOSC('/game_state', [current_state])
   ```

   (`current_state` is the same int you're already computing for
   `/remote/game_state` in Section 3 -- just fan it out to a second OSC Out
   DAT.)

3. Sanity check on the bench before the full six-board reflash: flash one
   board, watch its Serial output for `>> Listening for game-state
   broadcasts on UDP 9003`, then step your TD state through Idle → Three →
   Two → One → Start → Gameplay and confirm the LEDs match the table above
   at each step (Gameplay needs an actual patch cord plugged in to see
   green/red -- otherwise all three sockets read NONE and stay off, which
   is also correct).

## 5b. Send player-active state to the boards

Board firmware also listens on the same UDP **9003** port for a
`/player_active` broadcast (**3 int32 args**, `[p1, p2, p3]` as 0/1) --
**this requires the same reflash** as Section 5 (see `question_game/CLAUDE.md`
Section 7D). Each board knows which player it belongs to (boards 1/2 = P1,
3/4 = P2, 5/6 = P3, same mapping as Section 4's Board index → panel note
above) and, when that player is inactive, shows Idle lighting no matter what
`/game_state` says -- so a 2-player game leaves the unused player's two
boards flickering idle throughout the whole match instead of running the
countdown/match lighting for nobody.

1. Reuse the same `oscout_boards` DAT from Section 5 -- no new OSC Out DAT
   needed, just a new address on the same port.
2. Give TD somewhere to remember the 3 players' active state so it can be
   read back by both an immediate send and the periodic timer. A `Base COMP`
   with `.store()`/`.fetch()` works well (called `player_active_holder`
   below); a Table DAT works too if you prefer.
3. In `set_player_active()` (Section 2's Callbacks DAT), store the value and
   immediately re-broadcast to the boards -- already shown inline in
   Section 2 above:

   ```python
   def set_player_active(player_num, is_active):
       # TODO: wire to your actual player-activation logic
       op('player_active_holder').store('player_%d' % player_num, bool(is_active))
       send_player_active_to_boards()

   def send_player_active_to_boards():
       holder = op('player_active_holder')
       p1 = 1 if holder.fetch('player_1', True) else 0
       p2 = 1 if holder.fetch('player_2', True) else 0
       p3 = 1 if holder.fetch('player_3', True) else 0
       op('oscout_boards').sendOSC('/player_active', [p1, p2, p3])
   ```

   Default each `fetch()` to `True` (matches the firmware's own default of
   all-active) so a board never gets a spurious idle-lock before TD has
   heard anything.

4. Also call `send_player_active_to_boards()` from the same 1-second timer
   that already sends `/game_state` (Section 3/5), so a board that reboots
   mid-game (or missed a packet) still converges on the correct state within
   a second, rather than waiting for the next actual toggle. That function
   lives in `oscin1`'s Callbacks DAT (a different DAT/Python module than this
   Timer's CHOP Execute DAT), so reach across with `.module`:

   ```python
   # Same onCycle callback as Section 3/5, appended
   op('oscin1').module.send_player_active_to_boards()
   ```

5. Sanity check on the bench: with a board flashed and player-active wiring
   done, toggle a player OFF on the remote page while that board's state is
   Idle, then step the TD state through Three → Two → One → Gameplay -- the
   board should stay on flickering-green idle lighting the whole time
   instead of following the countdown/match lighting. Toggle the player back
   ON and confirm the board immediately starts following `/game_state`
   again on the next send.

## 5c. Report player-active state back to the remote controller

The remote page's ON/OFF display was previously just the *server's own
memory* of the last `/remote/player/<n>` command it sent -- TD never
actually confirmed what the real state was. This is wrong the moment the
two disagree: **the Node server's player state resets to all-OFF on every
restart**, regardless of what TD still has active, so a restart mid-show
would show every player OFF on the page even with a live game running.

Fix: TD reports the same `player_active_holder` values it already computes
for Section 5b back to the remote controller too -- same values, one more
destination. `state.players` on receipt becomes authoritative (overwrites
whatever the server locally assumed), so a fresh server always converges to
the truth within about a second of TD's next send.

1. No new OSC Out DAT needed -- reuse `oscout_remote` (already sending
   `/remote/heartbeat` and `/remote/game_state`, port 9002).
2. Add a second send function alongside `send_player_active_to_boards()`
   (Section 5b, `oscin1`'s Callbacks DAT):

   ```python
   def send_player_active_to_remote():
       holder = op('player_active_holder')
       p1 = 1 if holder.fetch('player_1', True) else 0
       p2 = 1 if holder.fetch('player_2', True) else 0
       p3 = 1 if holder.fetch('player_3', True) else 0
       op('oscout_remote').sendOSC('/remote/player_active', [p1, p2, p3])
   ```

3. Call it everywhere `send_player_active_to_boards()` is already called --
   both the immediate send in `set_player_active()` and the periodic one in
   the Timer's CHOP Execute DAT:

   ```python
   def set_player_active(player_num, is_active):
       # TODO: wire to your actual player-activation logic
       op('player_active_holder').store('player_%d' % player_num, bool(is_active))
       send_player_active_to_boards()
       send_player_active_to_remote()
   ```

   ```python
   # Same onCycle callback as Section 3/5/5b, appended
   op('oscin1').module.send_player_active_to_remote()
   ```

4. Sanity check: restart the Node server (close the "GSX Remote Controller"
   console window, let the watchdog relaunch it -- see `DEPLOYMENT.md`)
   while a player is toggled ON in TD. The remote page should show that
   player ON again within about a second of the fresh server coming up,
   without needing anyone to touch the page.

## 6. Firewall

Since everything above uses `127.0.0.1` (remote server and TouchDesigner on
the same PC), Windows Firewall shouldn't need any changes for the OSC
traffic. The only inbound rule you may need is for the **web page's HTTP
port** (default `8080`) so other devices on the LAN can reach it — Node will
prompt for this automatically the first time it runs, if the popup doesn't
appear, allow `node.exe` for Private networks.

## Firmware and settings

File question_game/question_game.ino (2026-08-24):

#include <Arduino.h>
#include <SPI.h>
#include <SD.h>
#include <ETH.h>

enum LEDState { LED_OFF, LED_RED, LED_GREEN, LED_YELLOW };

// --- LED BRIGHTNESS ---
// PWM duty cycle per state: 0 (off) - 255 (full brightness). Tweak to taste.
const int LED_BRIGHTNESS_FULL = 255;                    // red / green
const int LED_BRIGHTNESS_YELLOW_RED = LED_BRIGHTNESS_FULL / 4;   // yellow's red die, quarter brightness
const int LED_BRIGHTNESS_YELLOW_GREEN = LED_BRIGHTNESS_FULL / 8; // yellow's green die, eighth brightness

// --- ANALOG PIN DEFINITIONS ---
// CH1: GPIO 1 | CH2: GPIO 2 | CH3: GPIO 3
const int ANALOG_PINS[3] = { 1, 2, 3 }; 

// --- LED GPIO DEFINITIONS ---
// CH1 (Socket 1)
// NOTE: was originally GPIO35/34, which sit inside Waveshare's documented
// "GPIO33-37 internally occupied" range (see ESP32-S3-ETH wiki FAQ) -- driving
// those as outputs was corrupting state that later crashed SD.begin() with an
// Interrupt WDT panic (confirmed independently on both 34 and 35). Moved to
// GPIO42/45 -- neither overlaps SD, Ethernet, analog inputs, the other
// channels' LEDs, or the bad 33-37 range.
const int CH1_RED   = 45;
const int CH1_GREEN = 42;

// CH2 (Socket 2) 
const int CH2_RED   = 48;
const int CH2_GREEN = 47;

// CH3 (Socket 3)
const int CH3_RED   = 39;
const int CH3_GREEN = 38;

// --- SD CARD PIN DEFINITIONS ---
// Waveshare ESP32-S3-ETH onboard TF card slot. Uses the default global SPI
// object (not a separately-hosted SPIClass) -- an explicit SPIClass(FSPI)
// instance was found to hang SD.begin() on this board, even though the pins
// and card were confirmed good via an isolated test with the default object.
const int SD_SCK  = 7;
const int SD_MISO = 5;
const int SD_MOSI = 6;
const int SD_CS   = 4;

// --- MULTI-DEVICE CONFIG (SAME FIRMWARE, SIX PHYSICAL BOARDS) ---
// Each board's SD card carries a small device.cfg naming which of the six
// Waveshare units it is (1-6). That index selects which 3 rows of
// answer_table.tsv (also copied onto the SD card) become this board's
// correctAnswers[]. Devices 1/2 serve panel P1 (questions 1-3 / 4-6),
// devices 3/4 serve panel P2, devices 5/6 serve panel P3.
const char* DEVICE_CONFIG_FILE = "/device.cfg";
const char* ANSWER_TABLE_FILE  = "/answer_table.tsv";
int deviceIndex = 1; // fallback if SD card / config is missing

// --- ETHERNET / OSC TELEMETRY ---
// W5500 pins confirmed from Waveshare's own ESP32-S3-ETH wiki. Runs on its
// own SPI bus (HSPI) -- confirmed working standalone via ETH_Test.ino --
// separate from the SD card, which owns the default SPI object on GPIO4-7.
#define ETH_PHY_TYPE ETH_PHY_W5500
#define ETH_PHY_ADDR 1
#define ETH_PHY_CS   14
#define ETH_PHY_IRQ  10
#define ETH_PHY_RST  9
#define ETH_SPI_SCK  13
#define ETH_SPI_MISO 12
#define ETH_SPI_MOSI 11
SPIClass ethSPI(HSPI);
NetworkUDP udp;
uint32_t heartbeatCounter = 0; // increments every telemetry send, regardless of game state, so a listener can detect a live board even when its readings aren't changing
bool ethConnected = false;

// Static IP scheme: this board = 192.168.50.(10 + deviceIndex), e.g. device 4
// -> 192.168.50.14. Matches the addressing used when validating ETH_Test.ino.
IPAddress ethGateway(192, 168, 50, 1);
IPAddress ethSubnet(255, 255, 255, 0);
IPAddress ethDNS(192, 168, 50, 1);

// Where OSC telemetry gets sent. Defaults to the game controller PC's static
// IP; overridable per-board via an optional "controller_ip=" line in
// device.cfg if a board ever needs to report somewhere else.
IPAddress controllerIP(192, 168, 50, 100);
const uint16_t OSC_PORT = 9000;

// Incoming game-state channel (TD -> boards). TD broadcasts the current
// game state to 192.168.50.255 on this port; every board listens and reacts
// with lighting effects (see applyGameStateLighting() below).
const uint16_t STATE_LISTEN_PORT = 9003;
int currentGameState = 1; // 1 = Idle, matches the same 1-7 convention used elsewhere; safe default until TD sends real state

// Which of the 3 players this board belongs to (1-3), derived from
// deviceIndex once it's known: boards 1/2 -> P1, 3/4 -> P2, 5/6 -> P3.
// Set in setup(), right after deviceIndex is finalized.
int myPlayer = 1;

// Whether each of the 3 players is currently active in the game (a
// multiplayer variant may not use all three). TD broadcasts this alongside
// /game_state -- see checkForStateUpdate(). Defaults to all-active so a
// board's behavior is unchanged until/unless TD actually sends this.
bool playerActive[3] = { true, true, true };

// Per-player round result, broadcast by TD alongside /game_state once a
// round resolves -- see checkForStateUpdate() and applyResultEffect() below.
// 0=Try Again, 1=Winner, 2=2nd place, 3=3rd place. -1 means no result has
// been received yet for that player (distinct from a real 0-3 value), so a
// board doesn't fire an effect off its own startup default.
int playerResult[3] = { -1, -1, -1 };

// --- RESULT LIGHTING EFFECTS ---
// Triggered when this board's own player's result value changes while in
// Gameplay/Results; held regardless of what's plugged in until the game
// state returns to Idle. See applyResultEffect()/startResultEffect() and the
// effectiveState handling in loop().
enum ResultEffect { EFFECT_NONE, EFFECT_WIN_CHASE, EFFECT_SECOND_CHASE, EFFECT_THIRD_CHASE, EFFECT_TRY_AGAIN_FLASH };
ResultEffect activeEffect = EFFECT_NONE;
int lastEffectResult = -1;         // playerResult value the active effect (if any) was started for
unsigned long effectNextStepMs = 0;
int effectStep = 0;
const unsigned long CHASE_STEP_MS = 90;         // vegas-chase advance rate
const unsigned long TRY_AGAIN_FLASH_MS = 300;   // error-flash on/off period

struct SocketChannel {
  int analogPin;
  int redPin;
  int greenPin;
};

SocketChannel channels[3] = {
  { ANALOG_PINS[0], CH1_RED, CH1_GREEN },
  { ANALOG_PINS[1], CH2_RED, CH2_GREEN },
  { ANALOG_PINS[2], CH3_RED, CH3_GREEN }
};

struct ResistorRange {
  int minMV;
  int maxMV;
  const char* name;
};

// --- EMPIRICAL MEASURED RANGES (Normalized to nominal 3300mV scale) ---
// You can easily edit these values directly in your IDE if you observe drift!
const ResistorRange nominalRanges[10] = {
  { 112,  186, "470"  },
  { 250,  326, "1k"   },
  { 539,  608, "2.2k" },
  { 967, 1041, "4.7k" },
  { 1525, 1596, "10k"  },
  { 2078, 2131, "22k"  },
  { 2300, 2374, "33k"  },
  { 2401, 2551, "47k"  }, // Adjusted min to 2401 per empirical drift observation
  { 2615, 2682, "68k"  },
  { 2725, 2803, "100k" }
};

// Helper function to print exactly 4 characters for millivolts (e.g. " 205" or "2382")
void print4DigitMV(int mv) {
  if (mv < 1000) Serial.print(" ");
  if (mv < 100) Serial.print(" ");
  if (mv < 10) Serial.print(" ");
  Serial.print(mv);
}

// --- DECISION BOUNDARY THRESHOLD BIAS ---
// Tweak this value to shift how decision thresholds are calculated in gaps:
// 0.5 = Exact midpoint of the gap (50% / 50%)
// 0.3 = Shipped 30% of the gap (closer to lower resistor, giving the higher resistor more downward cushion)
const float THRESHOLD_BIAS = 0.3;

// --- DYNAMIC AUTO-SPAN CORRECTION FACTORS ---
// Continuously self-normalizes each ADC channel individually using empty sockets
float pinScaleFactors[3] = { 1.0, 1.0, 1.0 };

// --- CLASSIFICATION DEBOUNCE ---
// A patch cord passes through transient partial-contact states while it's being
// inserted (or removed), which can momentarily read as a different resistor value
// than the one actually seated. Requiring a classification to hold steady for
// DEBOUNCE_MS before accepting it filters out that insertion/removal noise.
// Timer-based (rather than counting loop passes) so this duration is exact
// regardless of the main loop's throttle delay.
const unsigned long DEBOUNCE_MS = 225;
int stableIndex[3] = { 10, 10, 10 };           // last accepted (debounced) classification per channel
int candidateIndex[3] = { 10, 10, 10 };        // classification currently being confirmed
unsigned long candidateSinceMs[3] = { 0, 0, 0 }; // when candidateIndex[i] first appeared

// --- IDLE "ETHERNET SWITCH" FLICKER ---
// While idle, each channel's LED randomly flashes green rather than sitting
// solid, mimicking an Ethernet switch port's link/activity LED. Non-blocking
// and per-channel independent: each channel rolls its own random on/off
// duration once its current one elapses, so the three don't flicker in sync.
// Mostly-on (long ON bursts, short OFF gaps) so the resting look reads as a
// live link light, not a mostly-dark one. A fraction of ON bursts render
// yellow instead of green to mimic a switch port's occasional amber/collision
// activity blip.
bool flickerOn[3] = { false, false, false };
bool flickerYellow[3] = { false, false, false };
unsigned long flickerNextToggleMs[3] = { 0, 0, 0 };
const int FLICKER_YELLOW_CHANCE_PCT = 20; // odds a given ON burst is yellow instead of green

void updateIdleFlicker() {
  unsigned long now = millis();
  for (int i = 0; i < 3; i++) {
    if (now >= flickerNextToggleMs[i]) {
      flickerOn[i] = !flickerOn[i];
      unsigned long duration;
      if (flickerOn[i]) {
        duration = random(300, 700);
        flickerYellow[i] = random(0, 100) < FLICKER_YELLOW_CHANCE_PCT;
      } else {
        duration = random(60, 180);
      }
      flickerNextToggleMs[i] = now + duration;
    }
  }
}

const char* getResistorName(int idx) {
  if (idx >= 0 && idx < 10) return nominalRanges[idx].name;
  return "NONE";
}

// --- GAME ANSWER CONFIGURATION ---
// Index mappings correspond to nominalRanges above:
// 0=470R, 1=1k, 2=2.2k, 3=4.7k, 4=10k, 5=22k, 6=33k, 7=47k, 8=68k, 9=100k, 10=NONE
// These are only the fallback/bench-test values used when no SD card (or no
// answer_table.tsv match) is found. Normally this array is overwritten at
// boot by loadAnswersFromSD() based on this board's device.cfg index.
int correctAnswers[3] = {
  3,  // CH1 correct answer is 4.7k Ohm (Index 3)
  7,  // CH2 correct answer is 47k Ohm  (Index 7)
  5   // CH3 correct answer is 22k Ohm  (Index 5)
};

// Works out which 3 question IDs (e.g. "P1q1", "P1q2", "P1q3") this board
// is responsible for, given its device.cfg index (1-6).
void computeQuestionIDs(int devIdx, String qIDs[3]) {
  int zeroBased = devIdx - 1;           // 0..5
  int panel = zeroBased / 2 + 1;        // 1,1,2,2,3,3
  int startQ = (zeroBased % 2) * 3 + 1; // 1 or 4
  for (int i = 0; i < 3; i++) {
    qIDs[i] = "P" + String(panel) + "q" + String(startQ + i);
  }
}

// Reads /device.cfg (key=value, e.g. "waveshare_index=3") from the SD card.
// Falls back to 1 and logs a warning if the file, key, or value is invalid.
int loadDeviceIndex() {
  File f = SD.open(DEVICE_CONFIG_FILE);
  if (!f) {
    Serial.print(">> WARNING: Could not open ");
    Serial.print(DEVICE_CONFIG_FILE);
    Serial.println(". Defaulting to waveshare_index=1.");
    return 1;
  }

  int idx = -1;
  while (f.available()) {
    String line = f.readStringUntil('\n');
    line.trim();
    if (line.startsWith("waveshare_index")) {
      int eq = line.indexOf('=');
      if (eq >= 0) {
        idx = line.substring(eq + 1).toInt();
      }
    }
  }
  f.close();

  if (idx < 1 || idx > 6) {
    Serial.println(">> WARNING: waveshare_index missing or out of range [1-6] in device.cfg. Defaulting to 1.");
    return 1;
  }
  return idx;
}

// Reads an optional "controller_ip=a.b.c.d" line from device.cfg to override
// where OSC telemetry gets sent. Leaves controllerIP at its default
// (192.168.50.100) if the file, key, or value is missing/invalid.
void loadControllerIP() {
  File f = SD.open(DEVICE_CONFIG_FILE);
  if (!f) return; // already warned about this in loadDeviceIndex()

  while (f.available()) {
    String line = f.readStringUntil('\n');
    line.trim();
    if (line.startsWith("controller_ip")) {
      int eq = line.indexOf('=');
      if (eq >= 0) {
        IPAddress parsed;
        String value = line.substring(eq + 1);
        value.trim();
        if (parsed.fromString(value)) {
          controllerIP = parsed;
        } else {
          Serial.print(">> WARNING: could not parse controller_ip value \"");
          Serial.print(value);
          Serial.println("\" in device.cfg. Keeping default.");
        }
      }
    }
  }
  f.close();
}

// Reads /answer_table.tsv from the SD card and fills correctAnswers[] with
// the "index" column of the 3 rows matching this device's question IDs.
// Returns true only if all 3 rows were found.
bool loadAnswersFromSD(int devIdx) {
  String qIDs[3];
  computeQuestionIDs(devIdx, qIDs);
  bool found[3] = { false, false, false };

  File f = SD.open(ANSWER_TABLE_FILE);
  if (!f) {
    Serial.print(">> WARNING: Could not open ");
    Serial.print(ANSWER_TABLE_FILE);
    Serial.println(" on SD card.");
    return false;
  }

  f.readStringUntil('\n'); // skip header row (question, answer, ohms, index)

  while (f.available()) {
    String line = f.readStringUntil('\n');
    line.trim();
    if (line.length() == 0) continue;

    int tab1 = line.indexOf('\t');
    int tab2 = line.indexOf('\t', tab1 + 1);
    int tab3 = line.indexOf('\t', tab2 + 1);
    if (tab1 < 0 || tab2 < 0 || tab3 < 0) continue; // malformed row, skip

    String question = line.substring(0, tab1);
    String idxStr = line.substring(tab3 + 1);
    idxStr.trim();

    for (int i = 0; i < 3; i++) {
      if (!found[i] && question == qIDs[i]) {
        correctAnswers[i] = idxStr.toInt();
        found[i] = true;
      }
    }
  }
  f.close();

  Serial.println(">> Device question assignments:");
  for (int i = 0; i < 3; i++) {
    Serial.print("   CH");
    Serial.print(i + 1);
    Serial.print(" = ");
    Serial.print(qIDs[i]);
    if (found[i]) {
      Serial.print("  -> answer index ");
      Serial.print(correctAnswers[i]);
      Serial.print(" (");
      Serial.print(getResistorName(correctAnswers[i]));
      Serial.println(")");
    } else {
      Serial.println("  -> NOT FOUND in answer_table.tsv (keeping fallback default)");
    }
  }

  return found[0] && found[1] && found[2];
}

int getComputedThreshold(int idx) {
  if (idx < 0 || idx >= 9) return 2921; // fallback
  int maxLower = nominalRanges[idx].maxMV;
  int minUpper = nominalRanges[idx + 1].minMV;
  int gap = minUpper - maxLower;
  return maxLower + (int)(gap * THRESHOLD_BIAS);
}

int getResistorIndex(int mv) {
  // Discard stray skin touch / ground noise below 75mV
  if (mv < 75) return 10; 

  // The open-circuit (NONE) boundary is computed above the 100k Max range
  // using your board's natural empty socket baseline target of 3040mV.
  int openThreshold = nominalRanges[9].maxMV + (int)((3040 - nominalRanges[9].maxMV) * THRESHOLD_BIAS);
  if (mv > openThreshold) return 10;

  int idx = 0;
  while (idx < 9) {
    int threshold = getComputedThreshold(idx);
    if (mv <= threshold) {
      return idx;
    }
    idx++;
  }
  return 9; // 100k Ohm
}

int readPinMV(int pin) {
  analogReadMilliVolts(pin); // Flush residual charge from ADC multiplexer
  delayMicroseconds(100);

  long sum = 0;
  for (int i = 0; i < 15; i++) {
    sum += analogReadMilliVolts(pin);
    delay(1);
  }
  return sum / 15;
}

void setLEDState(int redPin, int greenPin, LEDState state) {
  // Driving both dies of the bi-color LED at once reads as yellow/amber.
  // PWM (analogWrite) so each state's brightness is independently adjustable.
  int redLevel = 0;
  int greenLevel = 0;
  if (state == LED_RED) {
    redLevel = LED_BRIGHTNESS_FULL;
  } else if (state == LED_GREEN) {
    greenLevel = LED_BRIGHTNESS_FULL;
  } else if (state == LED_YELLOW) {
    redLevel = LED_BRIGHTNESS_YELLOW_RED;
    greenLevel = LED_BRIGHTNESS_YELLOW_GREEN;
  }
  analogWrite(redPin, redLevel);
  analogWrite(greenPin, greenLevel);
}

// Starts (or restarts) a result effect for the given playerResult value
// (0=Try Again, 1=Winner, 2=2nd, 3=3rd -- see playerResult[] declaration).
// Resets the animation phase so every new result starts from a clean beat.
void startResultEffect(int resultValue) {
  switch (resultValue) {
    case 1:  activeEffect = EFFECT_WIN_CHASE; break;
    case 2:  activeEffect = EFFECT_SECOND_CHASE; break;
    case 3:  activeEffect = EFFECT_THIRD_CHASE; break;
    default: activeEffect = EFFECT_TRY_AGAIN_FLASH; break; // 0, or any unexpected value
  }
  effectStep = 0;
  effectNextStepMs = millis();
}
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
void loop() {
  checkForStateUpdate();
  updateIdleFlicker();

  // Inactive players' boards never leave idle lighting, regardless of the
  // actual game state -- e.g. in a 2-player game, boards 5/6 (Player 3)
  // just keep flickering green through Three/Two/One/Gameplay/Results.
  // This only affects LED decisions below; readings/matching/telemetry are
  // unaffected.
  bool boardIdleOverride = !playerActive[myPlayer - 1];
  int effectiveState = boardIdleOverride ? 1 : currentGameState;

  // Result lighting effect (vegas chase / error flash): armed while in
  // Gameplay/Results and this board's own player's result changes, held
  // regardless of socket connections until effectiveState returns to Idle --
  // which also covers boardIdleOverride, so an inactive player's board never
  // fires one. See applyResultEffect()/startResultEffect() above.
  if (effectiveState == 1) {
    activeEffect = EFFECT_NONE;
    lastEffectResult = -1;
  } else if ((effectiveState == 6 || effectiveState == 7) &&
             playerResult[myPlayer - 1] != lastEffectResult) {
    lastEffectResult = playerResult[myPlayer - 1];
    startResultEffect(lastEffectResult);
  }

  bool allCorrect = true;
  bool matched[3] = { false, false, false };

  for (int i = 0; i < 3; i++) {
    int rawMV = readPinMV(channels[i].analogPin);

    // Continuous Auto-Calibration:
    // If raw voltage is in open-circuit range (above 2850mV), dynamically calibrate
    // this channel's scale factor against your board's natural target of 3040mV.
    if (rawMV > 2850) {
      pinScaleFactors[i] = 3040.0 / (float)rawMV;
    }

    // Apply scaling factor to get normalized voltage
    int normalizedMV = (int)(rawMV * pinScaleFactors[i]);

    int detectedIndex = getResistorIndex(normalizedMV);

    // Debounce: only accept a new classification once it has read consistently
    // for DEBOUNCE_MS milliseconds (see declaration above).
    if (detectedIndex != candidateIndex[i]) {
      candidateIndex[i] = detectedIndex;
      candidateSinceMs[i] = millis();
    } else if (millis() - candidateSinceMs[i] >= DEBOUNCE_MS) {
      stableIndex[i] = candidateIndex[i];
    }

    // Channel Connection Check: index 10 means the socket is empty (open circuit)
    bool isConnected = (stableIndex[i] != 10);

    // Channel Match Check: See if detected resistor matches the correct answer for this channel
    bool isMatch = isConnected && (stableIndex[i] == correctAnswers[i]);

    // Still deciding: the live reading hasn't yet been confirmed as the new
    // stable classification, so keep the LED off instead of jumping to red/green.
    bool isDeciding = (detectedIndex != stableIndex[i]);

    LEDState ledState;
    if (effectiveState == 6 || effectiveState == 7) {
      // Gameplay / Results: reflect actual connection data.
      ledState = LED_OFF;
      if (!isDeciding && isConnected) {
        ledState = isMatch ? LED_GREEN : LED_RED;
      }
    } else {
      // Idle / Three / Two / One / Start: lighting is state-driven, not reading-driven.
      ledState = countdownOrIdleLEDState(i, effectiveState);
    }
    // A held result effect (see above) takes over all 3 channels' LEDs at
    // once via applyResultEffect() below, overriding ledState here.
    if (activeEffect == EFFECT_NONE) {
      setLEDState(channels[i].redPin, channels[i].greenPin, ledState);
    }

    matched[i] = isMatch;
    if (!isMatch) {
      allCorrect = false;
    }

    Serial.print("CH");
    Serial.print(i + 1);
    Serial.print(":");

    // Print short name (e.g. "4.7k" or "NONE") aligned to exactly 5 characters
    // Uses the debounced stableIndex, not the raw instantaneous detectedIndex.
    const char* name = getResistorName(stableIndex[i]);
    Serial.print(name);
    int nameLen = strlen(name);
    for (int p = nameLen; p < 5; p++) {
      Serial.print(" ");
    }
    
    Serial.print("(");
    print4DigitMV(normalizedMV);
    Serial.print("mV) ");
    
    Serial.print(isMatch ? "[ OK ]" : "[ERR ]");
    
    if (i < 2) {
      Serial.print(" | ");
    }
  }

  // Render the held result effect (if any) across all 3 channels at once --
  // done after the per-channel loop above since it overrides, rather than
  // reads, each channel's LED.
  if (activeEffect != EFFECT_NONE) {
    applyResultEffect();
  }

  // GAME WIN CONDITION: Triggered only when all three channels match their correct answers simultaneously
  if (allCorrect) {
    Serial.print(" *** GAME SOLVED: ALL PATCHES CORRECT! ***");
  }

  Serial.println();

  sendGameStateOSC(stableIndex, matched, allCorrect);

  // Throttle delay. checkForStateUpdate() (top of loop) only gets called once
  // per pass, so this delay -- plus the ~45ms of ADC averaging above it -- is
  // also the worst-case latency between TD sending /game_state,
  // /player_active, or /player_result and this board's LEDs reflecting it.
  // Kept short (rather than the original 300ms) specifically so that's small
  // relative to the 1-second countdown states (Three/Two/One) on stage.
  delay(50);
}

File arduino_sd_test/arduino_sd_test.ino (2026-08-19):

// Minimal SD card isolation test for the Waveshare ESP32-S3-ETH onboard TF
// slot. Default global SPI object with custom pins, no other peripherals.
// Useful as a standalone sanity check if SD problems come up again.

#include <SPI.h>
#include <SD.h>

const int SD_CS   = 4;
const int SD_MISO = 5;
const int SD_MOSI = 6;
const int SD_SCK  = 7;

void writeFileToSD() {
  File f = SD.open("/waveshare.txt", FILE_WRITE);
  if (!f) {
    Serial.println("writeFileToSD: failed to open for writing");
    return;
  }
  f.println("Hello world from Waveshare");
  f.close();
  Serial.println("writeFileToSD: done");
}

void listFilesOnSD() {
  File root = SD.open("/");
  if (!root) {
    Serial.println("listFilesOnSD: failed to open root");
    return;
  }
  File entry = root.openNextFile();
  while (entry) {
    Serial.print("  ");
    Serial.print(entry.name());
    Serial.print("  ");
    Serial.println(entry.size());
    entry = root.openNextFile();
  }
  root.close();
}

void readFileFromSD(const char *path) {
  File f = SD.open(path);
  if (!f) {
    Serial.println("readFileFromSD: failed to open");
    return;
  }
  Serial.print("Contents of ");
  Serial.print(path);
  Serial.println(":");
  while (f.available()) {
    Serial.write(f.read());
  }
  f.close();
}

void setup() {
  Serial.begin(115200);
  delay(2000);
  Serial.println("\n--- SD isolation test starting ---");

  Serial.println(">> SPI.begin() ...");
  Serial.flush();
  SPI.begin(SD_SCK, SD_MISO, SD_MOSI, SD_CS);

  Serial.println(">> SD.begin() ...");
  Serial.flush();
  if (!SD.begin(SD_CS)) {
    Serial.println(">> SD.begin() FAILED");
    return;
  }

  Serial.println(">> SD.begin() OK");
  uint8_t cardType = SD.cardType();
  Serial.print("Card type: ");
  Serial.println(cardType);
  Serial.print("Card size (MB): ");
  Serial.println((uint32_t)(SD.cardSize() / (1024 * 1024)));

  writeFileToSD();
  Serial.println("Root directory listing:");
  listFilesOnSD();
  readFileFromSD("/waveshare.txt");

  Serial.println("--- SD isolation test complete ---");
}

void loop() {
}

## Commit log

2026-07-31 initial commit
    initial commit
    [answer_table.tsv, question_game.fzz]
2026-08-05 onsite testing
    [Protoboard.fzz]
2026-08-13 adding simpler board
    [Protoboardv2.fzz]
2026-08-17 updated answer key, building out screens
    [answer_table.tsv]
2026-08-17 reordering folder files
    [Protoboard.fzz, question_game_breadboard.fzz, question_game_schematic.fzz]
2026-08-17 updating timer
2026-08-18 added ohms to answer table, groundwork for variable player
    [answer_table.tsv]
2026-08-18 working on config
    [answer_table.tsv, config_panel_1a.tsv, config_panel_1b.tsv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]
2026-08-19 tested all boards and sockets with config files
    [config_panel_1a.tsv, config_panel_1b.tsv, config_panel_2a.tsv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]
2026-08-19 updated fritzing, input comms from breadboard to td, updated game logic based on actual signals, multiplayer variable player mode
    [question_game_breadboard.fzz]
